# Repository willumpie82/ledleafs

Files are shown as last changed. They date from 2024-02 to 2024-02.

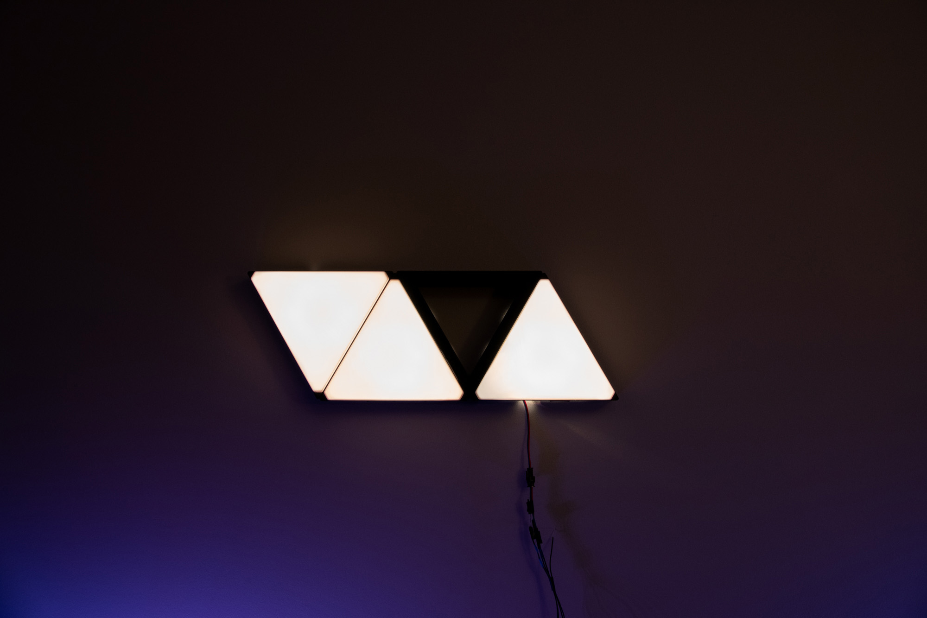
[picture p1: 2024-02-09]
CAD/images/Pres_3.jpg

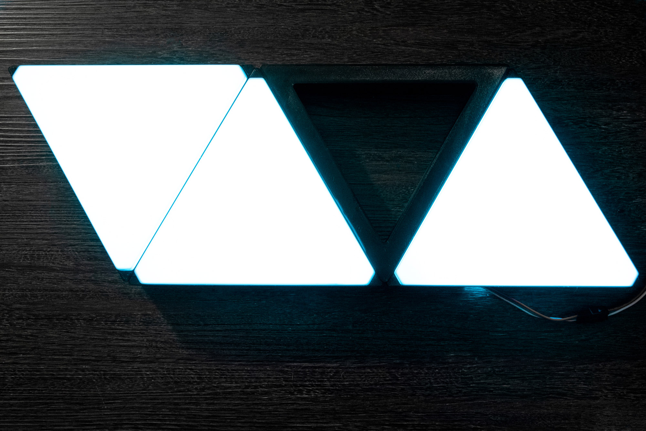
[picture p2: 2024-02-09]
CAD/images/Manuel_9.jpg

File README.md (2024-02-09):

# ledleafs

Please note, this repo is shared as-is, no guarantees

a few attention points to the schematic and pcb that might need fixing
- check your LEDs, WS2812(RGB) vs SK6812(RGBWW), the footprint is 180deg rotated, no change in PCB needed just rotate the components (PCB desgin = WS2812)
- esp32C3 super micro doesn't want to boot when moounted with all pads (no clue why, nothing is connected except power and GPIO), I swapped it out for a Seeed-studio XAIO ESP32 with external antenna
- level shifter not assembled, just hot-wired GPIO of ESP directly to LED1
- no VEML (light sensor support in WLED)

parts used (non affiliate links)
- Conenctors: [https://vi.aliexpress.com/item/1005006028155508.html](https://vi.aliexpress.com/item/1005006028155508.html)https://vi.aliexpress.com/item/1005006028155508.html
- Switches: [https://vi.aliexpress.com/item/4001161324412.html](https://vi.aliexpress.com/item/4001161324412.html)https://vi.aliexpress.com/item/4001161324412.html
- LEDs: [https://vi.aliexpress.com/item/32641663497.html](https://vi.aliexpress.com/item/32641663497.html)https://vi.aliexpress.com/item/32641663497.html
- wires: [https://vi.aliexpress.com/item/1005006125634331.html](https://vi.aliexpress.com/item/1005006125634331.html)https://vi.aliexpress.com/item/1005006125634331.html

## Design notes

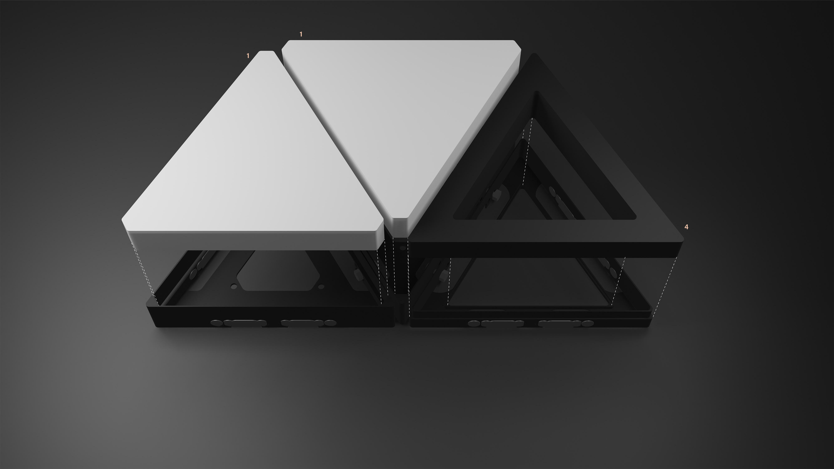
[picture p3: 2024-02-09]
CAD/images/Manuel_3.jpg

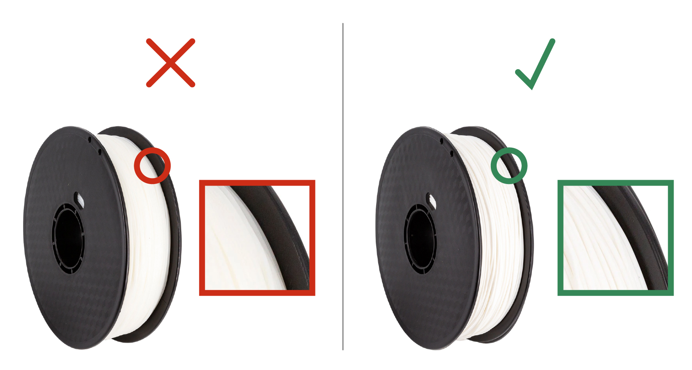
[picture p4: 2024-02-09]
CAD/images/Warning.jpg

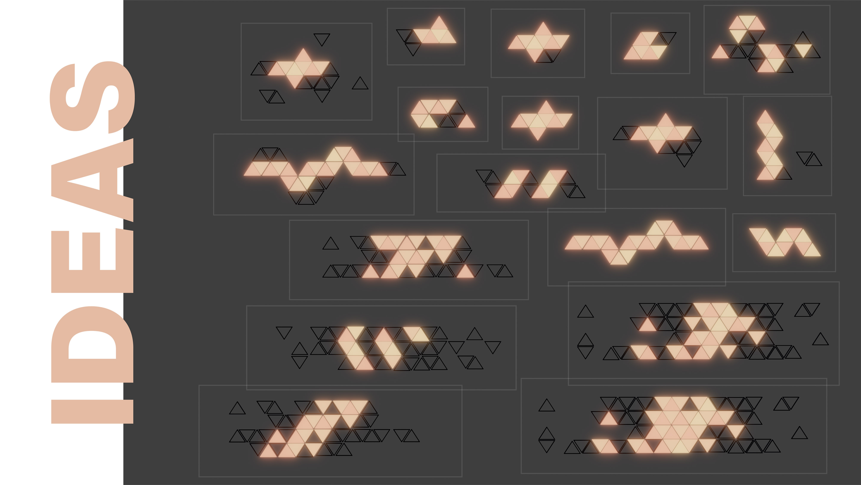
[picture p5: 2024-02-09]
CAD/images/Ideas.jpg

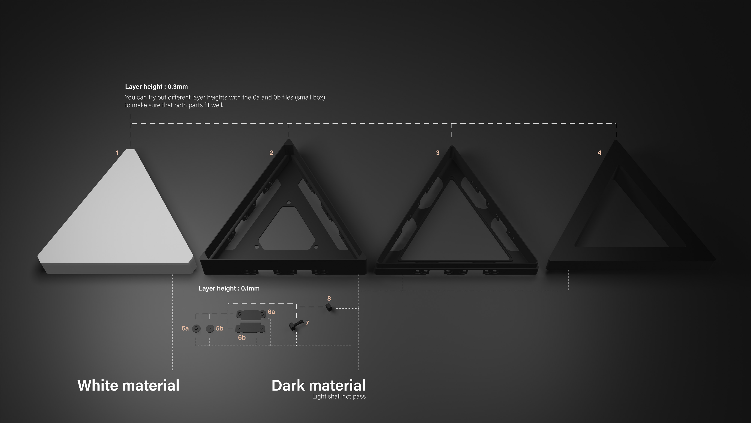
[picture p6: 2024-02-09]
CAD/images/Manuel_1.jpg

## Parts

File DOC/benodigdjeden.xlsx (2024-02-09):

part | need | got | todo | kleur | gram | gram needed
blanks
lid | 10 | 4 | 6 | zwart | 37 | 222
frame 1con | 1 | 4 | 0 | zwart
frame 2con | 9 | 2 | 7 | zwart | 29.5 | 206.5
lights
lid | 19 | 16 | 3 | wit | 30 | 90
frame 1con | 1 | 1 | 0 | zwart
frame 2con | 13 | 9 | 4 | zwart | 50 | 200
frame 3con | 5 | 5 | 0 | zwart
PCB | 19 | 0 | 19
montage
schroeven | 64 | 20 | 44 | zwart | 0.45 | 20
moeren | 64 | 20 | 44 | zwart
aankopen
rol zwarte fillament pla matte | 2 | 16.76
rol witte filament | 1 | 16.75
pcbs
onderdelen

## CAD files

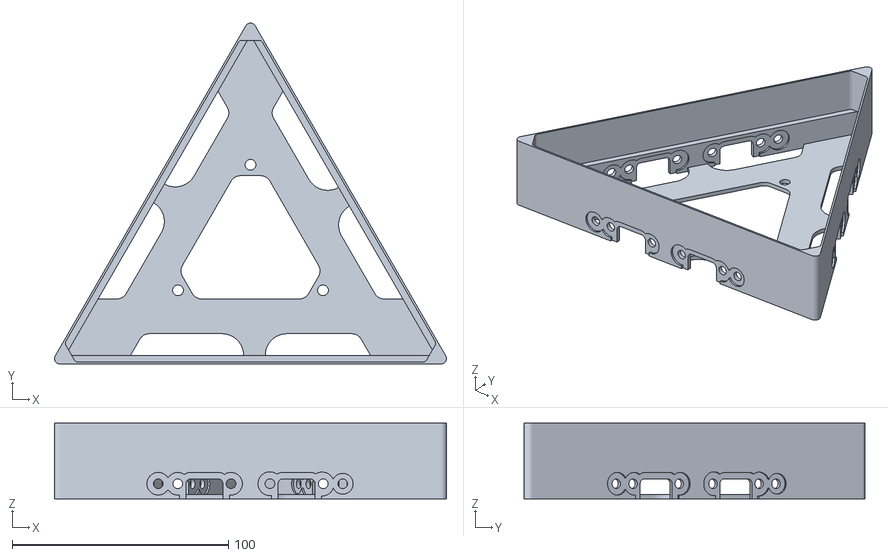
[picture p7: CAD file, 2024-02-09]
CAD/files/2_with_connection_build_plate_adhesion.stl
181.1 x 157.5 x 35.0

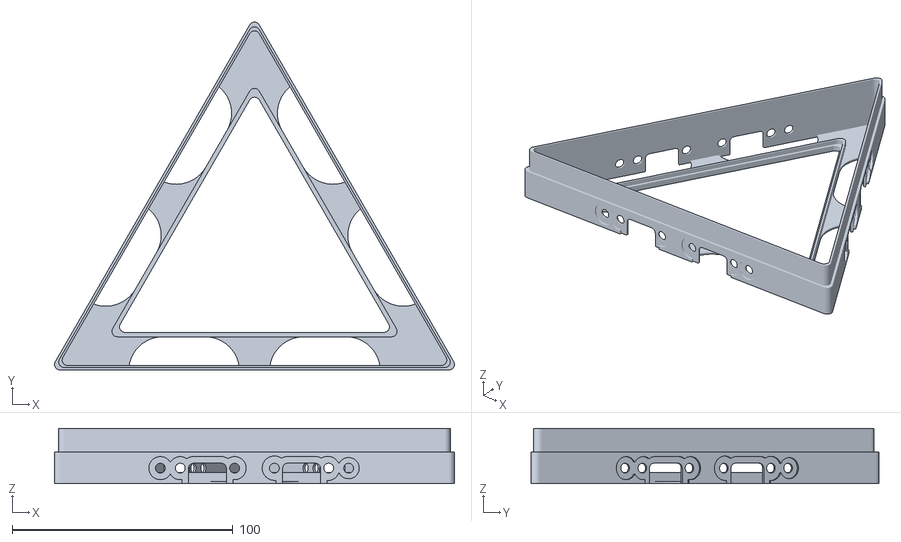
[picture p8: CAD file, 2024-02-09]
CAD/files/3.stl
181.1 x 157.5 x 25.0

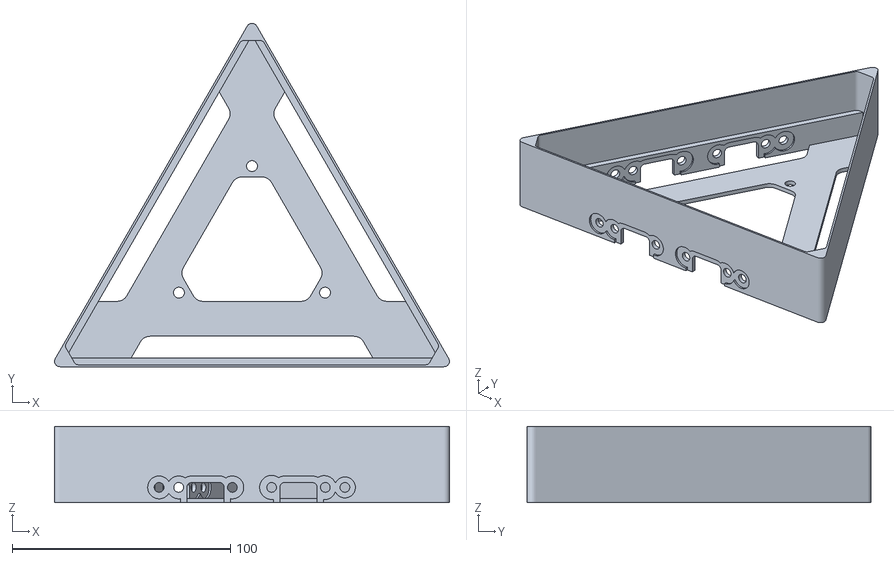
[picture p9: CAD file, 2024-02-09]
CAD/files/2_with_only_two_ties.stl
181.1 x 157.5 x 35.0

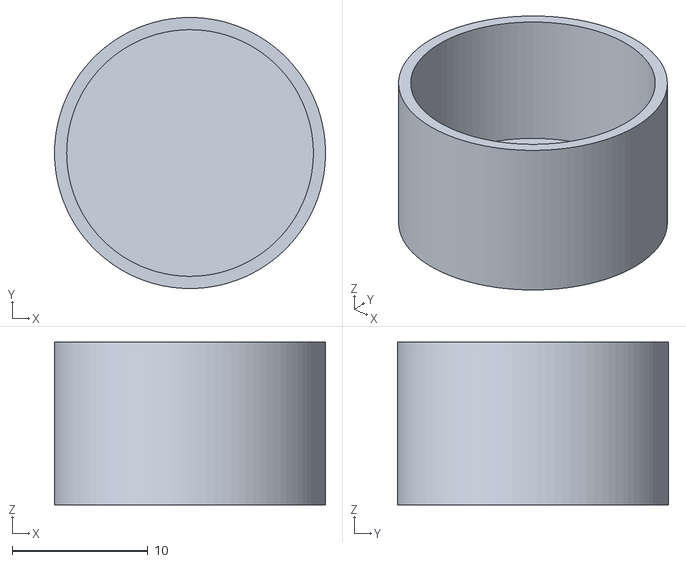
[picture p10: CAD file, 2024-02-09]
CAD/files/0a.stl
20.0 x 20.0 x 12.0

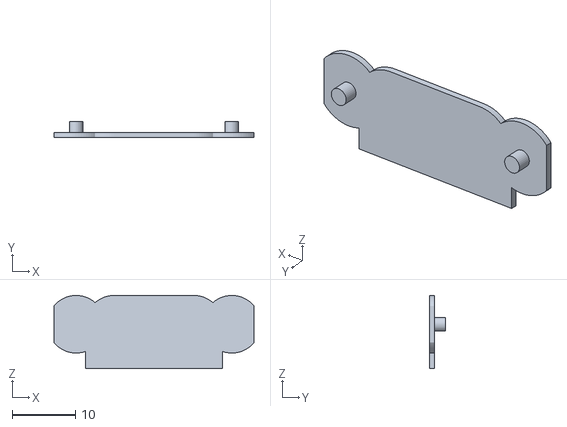
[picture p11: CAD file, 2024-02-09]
CAD/files/6b.stl
31.6 x 2.60 x 11.6

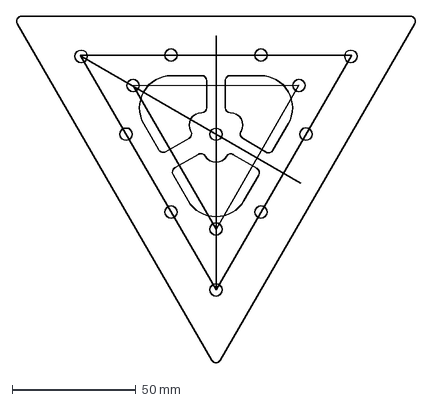
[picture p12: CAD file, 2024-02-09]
CAD/files/leds.dxf
161.2 x 140.0 mm

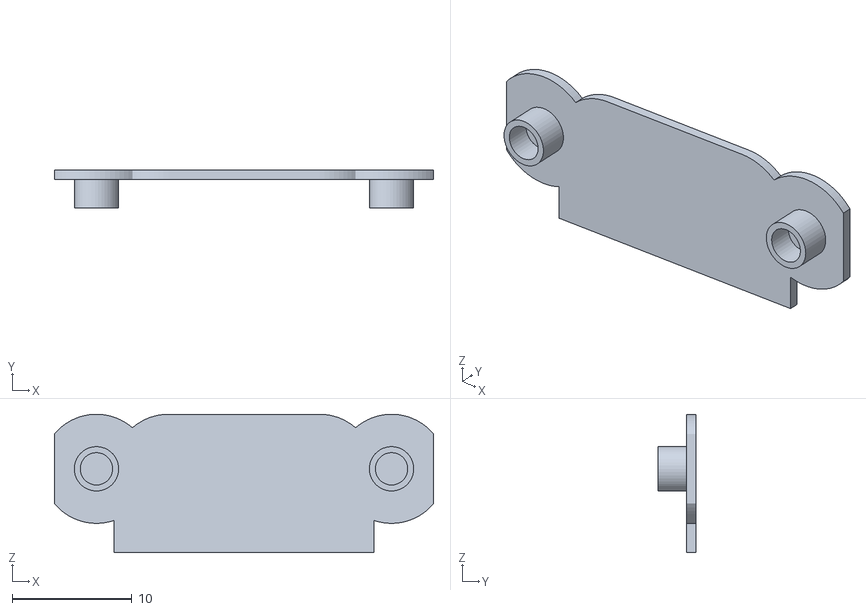
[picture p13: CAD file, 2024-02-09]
CAD/files/6a.stl
31.6 x 3.20 x 11.6

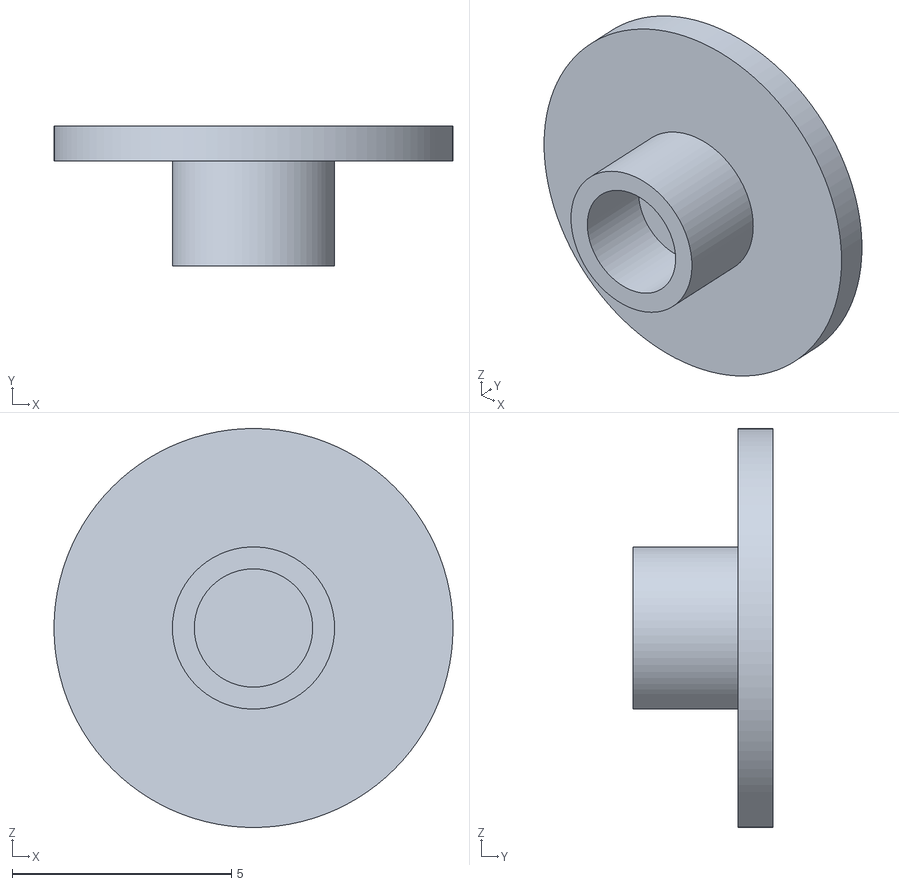
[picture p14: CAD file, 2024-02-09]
CAD/files/5a.stl
9.10 x 3.20 x 9.10

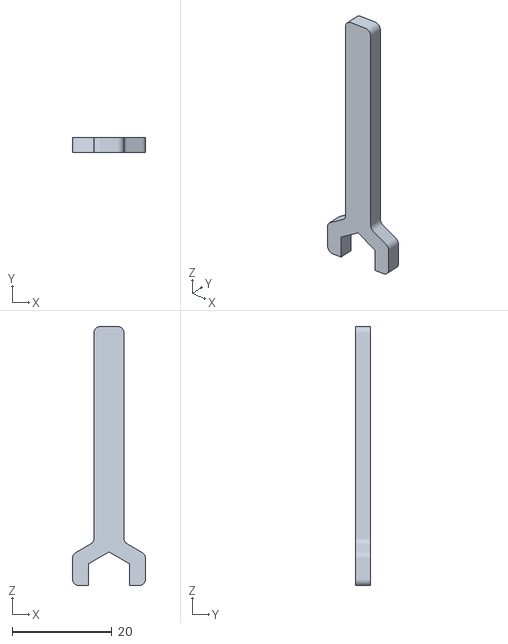
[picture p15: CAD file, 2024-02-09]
CAD/files/tool.stl
14.7 x 3.00 x 52.0

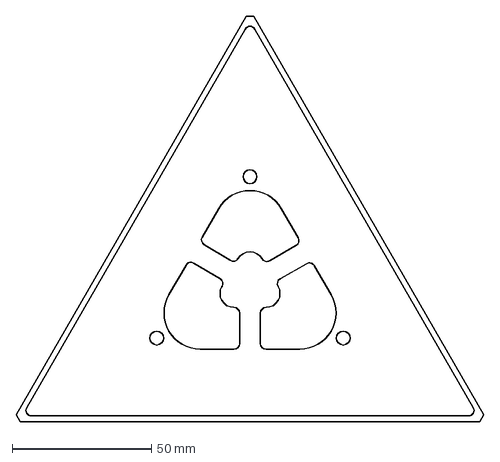
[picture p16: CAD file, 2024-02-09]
CAD/files/nanoleafPCB_dxf.dxf
168.0 x 145.5 mm

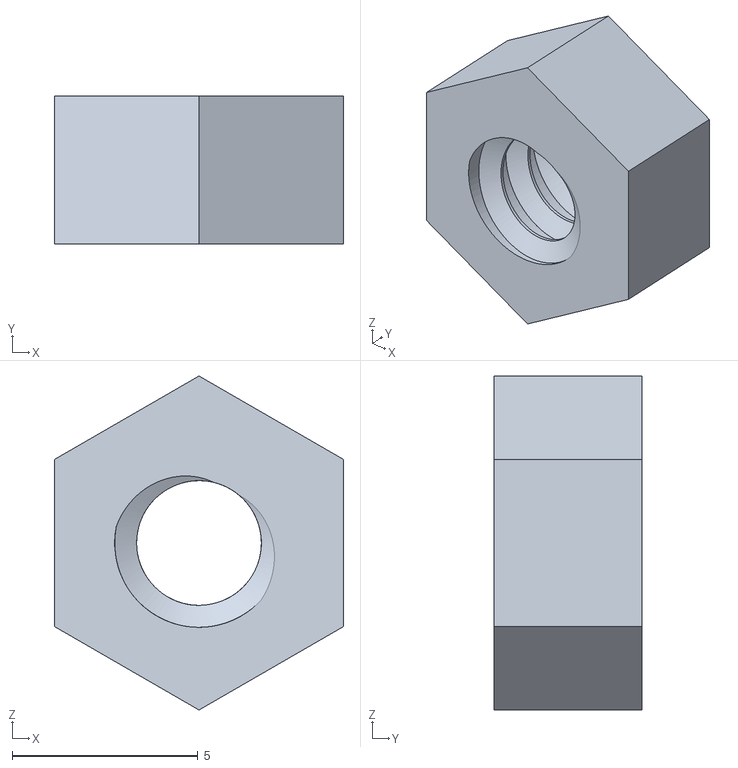
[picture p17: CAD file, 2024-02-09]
CAD/files/8.stl
7.79 x 4.00 x 9.00

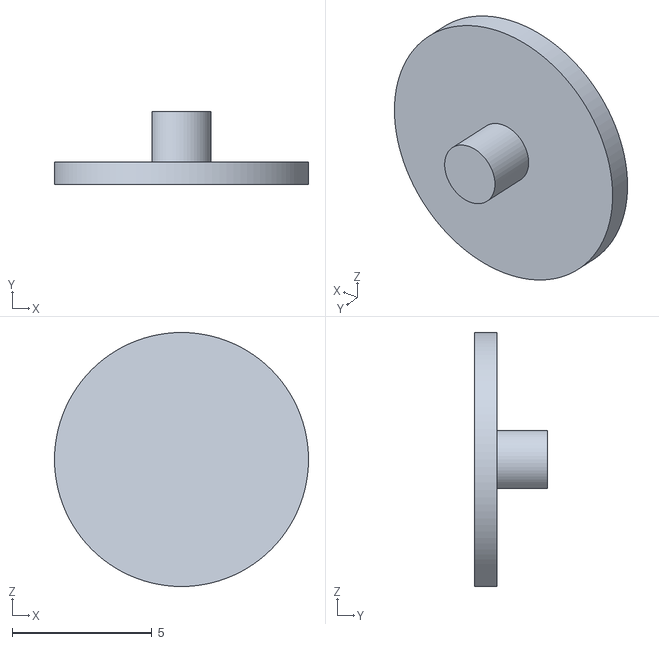
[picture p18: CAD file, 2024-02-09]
CAD/files/5b.stl
9.10 x 2.60 x 9.10

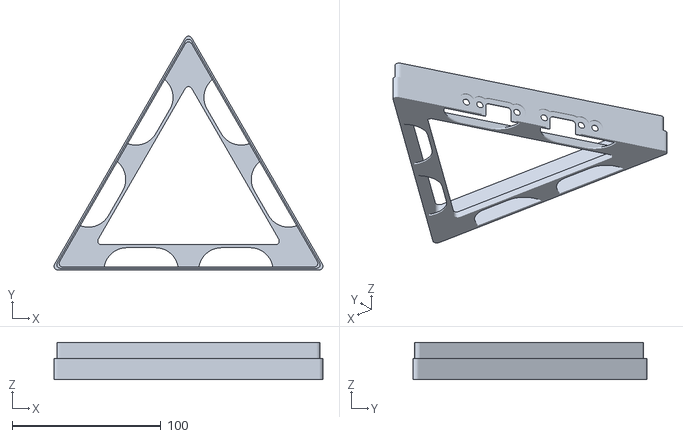
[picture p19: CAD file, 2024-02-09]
CAD/files/3_with_only_one_tie.stl
181.1 x 157.5 x 25.0

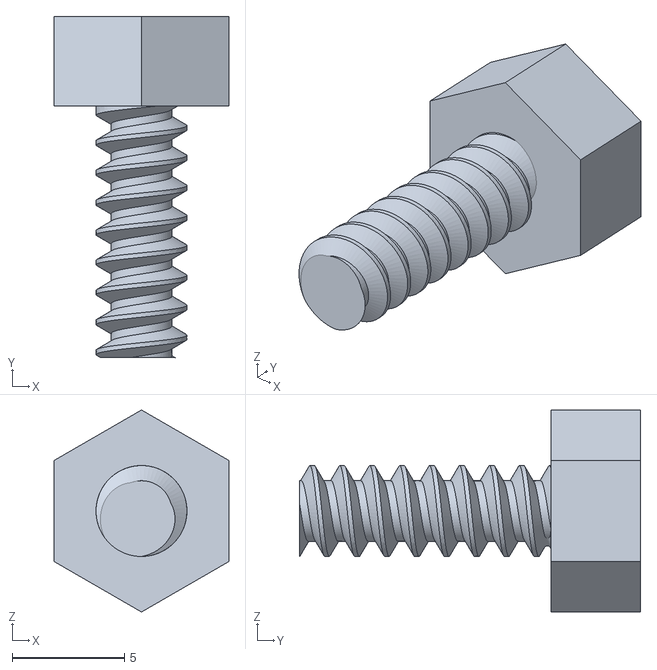
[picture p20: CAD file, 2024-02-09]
CAD/files/7.stl
7.79 x 15.2 x 9.00

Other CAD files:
CAD/files/2_with_only_one_tie.stl
CAD/files/3_with_only_two_ties.stl
CAD/files/1.stl
CAD/files/2.stl
CAD/files/0b.stl
CAD/files/4.stl
CAD/files/PCB.f3d

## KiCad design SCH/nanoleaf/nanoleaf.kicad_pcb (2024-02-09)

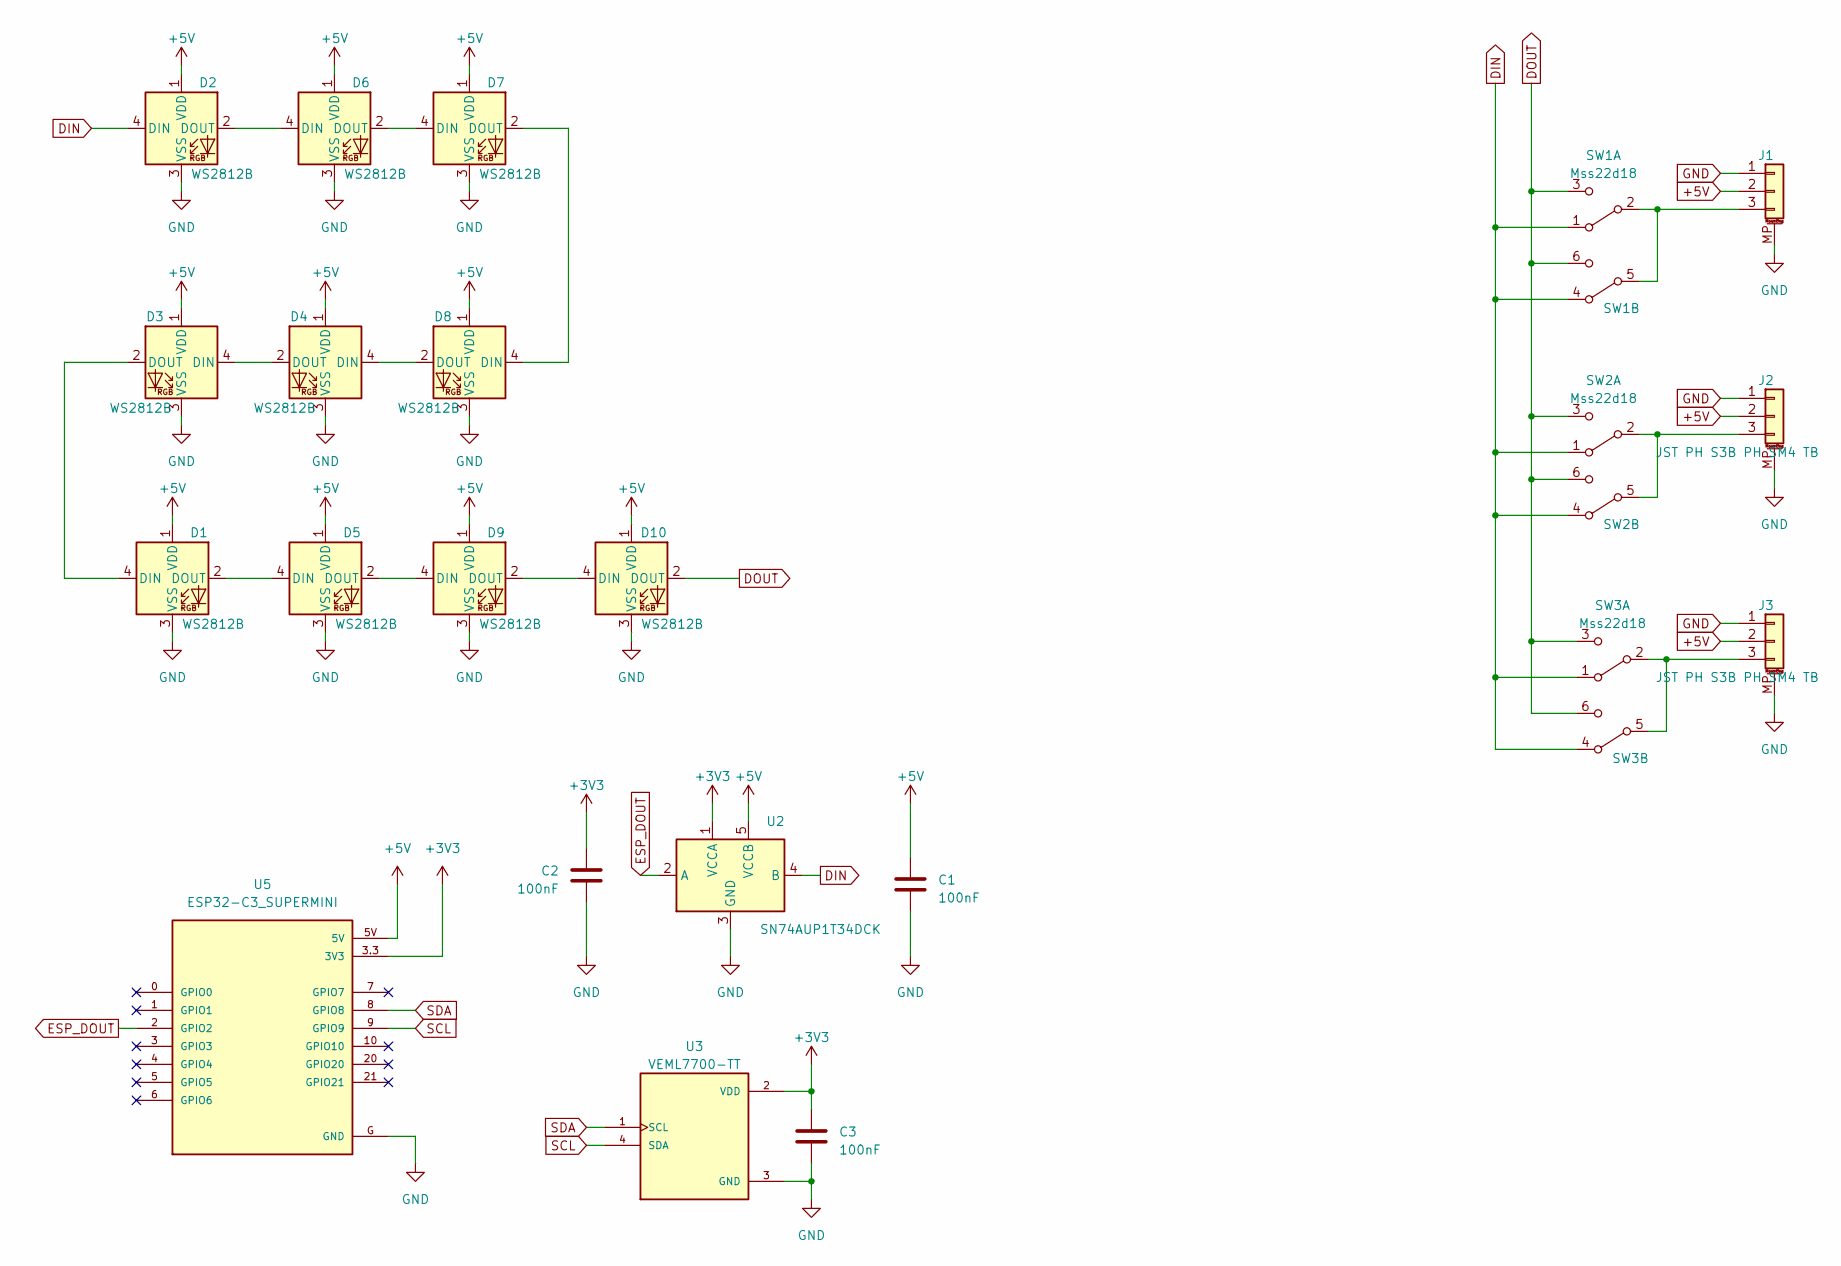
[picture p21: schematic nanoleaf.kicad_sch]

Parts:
C1, C2, C3: 100nF; C_0603_1608Metric
D1, D2, D3, D4, D5, D6, D7, D8, D9, D10: WS2812B; LED_WS2812B_PLCC4_5.0x5.0mm_P3.2mm
J1, J2, J3: JST PH S3B PH SM4 TB; JST_PH_S3B-PH-SM4-TB_1x03-1MP_P2.00mm_Horizontal
SW1, SW2, SW3: Mss22d18; SW_DPDT_CK_JS202011SCQN
U2: SN74AUP1T34DCK; SOT-353_SC-70-5
U3: VEML7700-TT; XDCR_VEML7700-TT; PARTREV 1.6
U5: ESP32-C3_SUPERMINI; MODULE_ESP32-C3_SUPERMINI_1

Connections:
+3V3: C2.1, C3.1, U2.1 (VCCA), U3.2 (VDD), U5.3.3 (3V3)
+5V: C1.1, D1.1 (VDD), D2.1 (VDD), D3.1 (VDD), D4.1 (VDD), D5.1 (VDD), D6.1 (VDD), D7.1 (VDD), D8.1 (VDD), D9.1 (VDD), D10.1 (VDD), J1.2, J2.2, J3.2, U2.5 (VCCB), U5.5V
DIN: D2.4 (DIN), SW1.1 (A), SW1.4 (A), SW2.1 (A), SW2.4 (A), SW3.1 (A), SW3.4 (A), U2.4 (B)
DOUT: D10.2 (DOUT), SW1.3 (C), SW1.6 (C), SW2.3 (C), SW2.6 (C), SW3.3 (C), SW3.6 (C)
ESP_DOUT: U2.2 (A), U5.2 (GPIO2)
GND: C1.2, C2.2, C3.2, D1.3 (VSS), D2.3 (VSS), D3.3 (VSS), D4.3 (VSS), D5.3 (VSS), D6.3 (VSS), D7.3 (VSS), D8.3 (VSS), D9.3 (VSS), D10.3 (VSS), J1.1, J1.MP (MountPin), J2.1, J2.MP (MountPin), J3.1, J3.MP (MountPin), U2.3 (GND), U3.3 (GND), U5.G (GND)
unnamed: D1.4 (DIN), D3.2 (DOUT)
unnamed: D1.2 (DOUT), D5.4 (DIN)
unnamed: D2.2 (DOUT), D6.4 (DIN)
unnamed: D3.4 (DIN), D4.2 (DOUT)
unnamed: D4.4 (DIN), D8.2 (DOUT)
unnamed: D5.2 (DOUT), D9.4 (DIN)
unnamed: D6.2 (DOUT), D7.4 (DIN)
unnamed: D7.2 (DOUT), D8.4 (DIN)
unnamed: D9.2 (DOUT), D10.4 (DIN)
unnamed: J1.3, SW1.2 (B), SW1.5 (B)
unnamed: J2.3, SW2.2 (B), SW2.5 (B)
unnamed: J3.3, SW3.2 (B), SW3.5 (B)
SCL: U3.4 (SDA), U5.9 (GPIO9)
SDA: U3.1 (SCL), U5.8 (GPIO8)

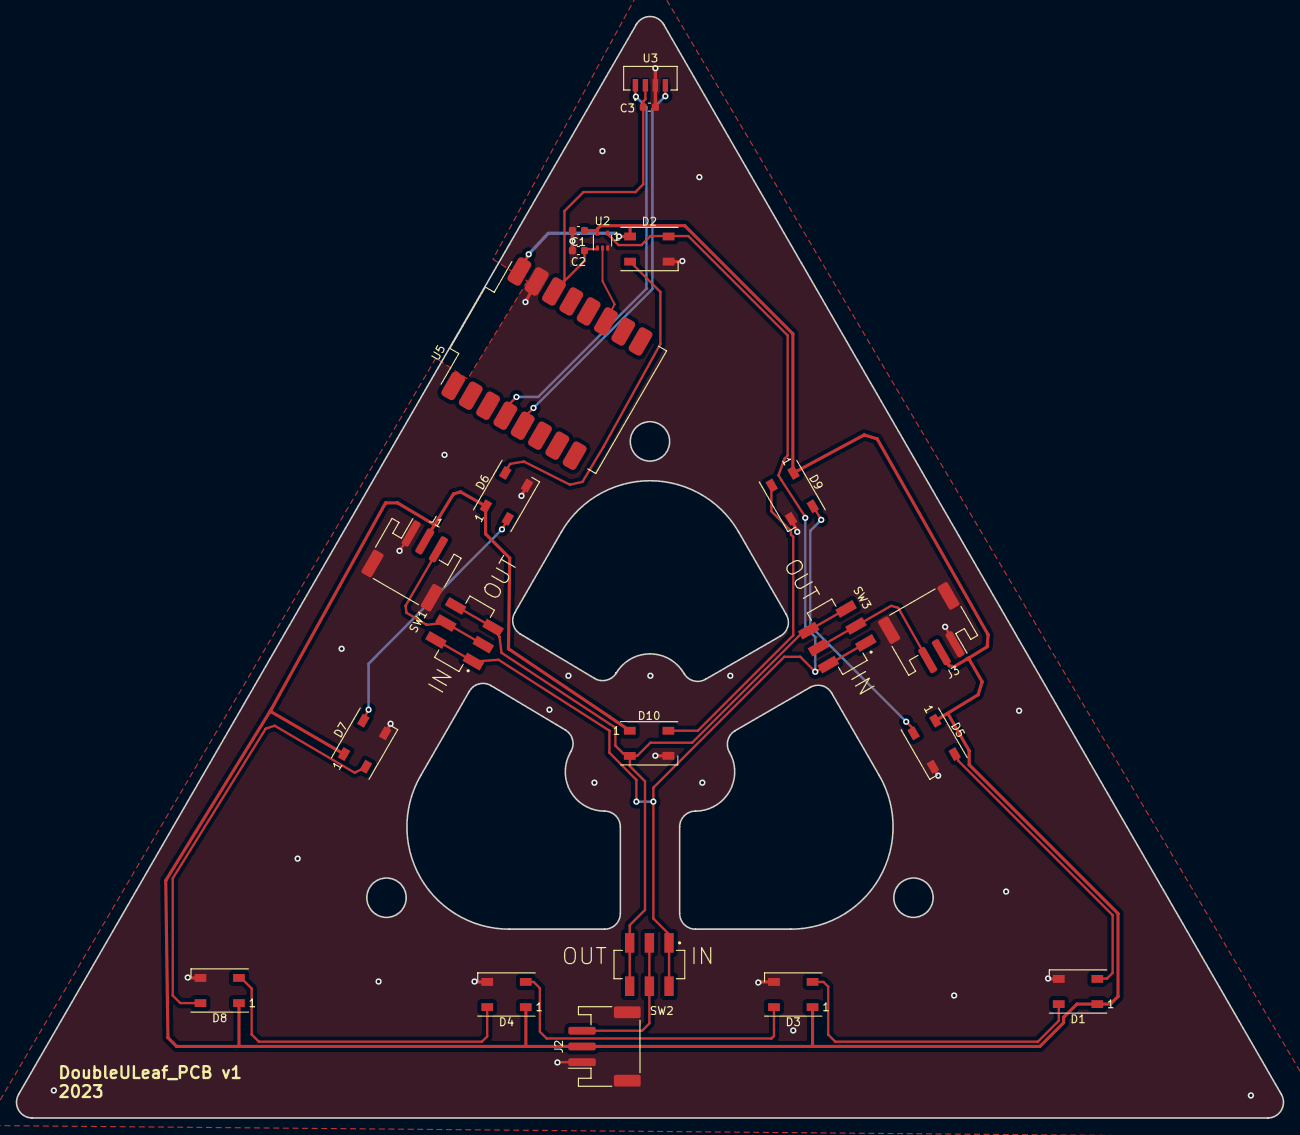
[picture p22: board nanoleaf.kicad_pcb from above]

Board: 2 copper layers, 161.0 x 140.0 mm, 22 parts (0 on the bottom side), 20 nets.

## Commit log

2024-02-09 production files
    [nanoleaf.kicad_pcb]
2024-02-09 switch and jst PH
    [nanoleaf.kicad_pcb, nanoleaf.kicad_sch]
2024-02-09 added gcode and stock
    [benodigdjeden.xlsx]
2024-02-09 Add doc
    [benodigdjeden.xlsx]
